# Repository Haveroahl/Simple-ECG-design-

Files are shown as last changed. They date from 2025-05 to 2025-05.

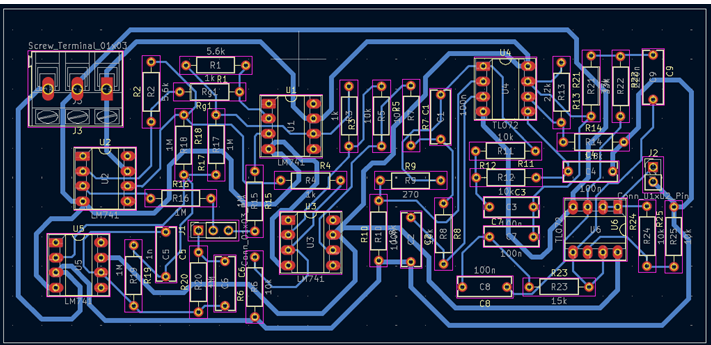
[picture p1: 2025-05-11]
Layout_ECG.png

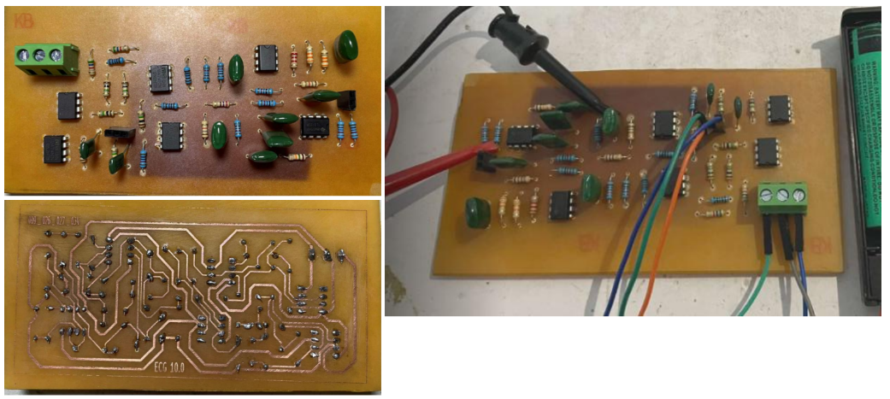
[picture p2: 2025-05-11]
PCB_ECG.png

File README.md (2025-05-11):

# Simple ECG design
#This is a group project focused on designing a simple ECG signal acquisition circuit. The initial design used the u741 operational amplifier, and later improvements were made using the TL072 for enhanced performance.

# Flow 
• Researched and analyzed the components of a basic ECG circuit, including an instrumentation amplifier, a 4th-order low-pass Sallen-Key filter, and a twin-T notch filter using the u741 OpAmp.<br>
• Calculated appropriate component values for circuit design, simulated ECG waveforms with added noise using LTspice, and tested the circuit on a breadboard.<br>
• Designed schematic and PCB layout, and assembled the circuit on a PCB.

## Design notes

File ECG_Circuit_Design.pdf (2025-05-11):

# THIẾT KẾ MẠCH Y SINH ECG

GIÁO VIÊN HƯỚNG DẪN: LÊ ĐỨC HÙNG

HỌ VÀ TÊN | MSSV | NHIỆM VỤ
Lê Minh Đức | 22200034 | Thiết kế, testboard, vẽ schematic, vẽ layout
Lê Thành Đạt | 22200026 | Testboard, hàn mạch PCB, cung cấp linh kiện
Nguyễn Hữu Đạt | 22200027 | Thiết kế, mô phỏng, testboard, hàn mạch PCB
Đặng Gia Bảo | 22200009 | Tìm hiểu nội dung, tính toán, thiết kế presentation

## 3. Ráp mạch: - Testboard - PCB - Kiểm tra

### 2. Thiết kế mạch: - Mạch khuếch đại vi sai - Mạch lọc thấp qua - Mạch lọc Notch - Mô phỏng

# MỤC LỤC

### 1. Giới thiệu: - Mục tiêu đồ án - Tổng quan về ECG

## 4. Kết luận: - Đánh giá - Hướng phát triển

# 1. GIỚI THIỆU

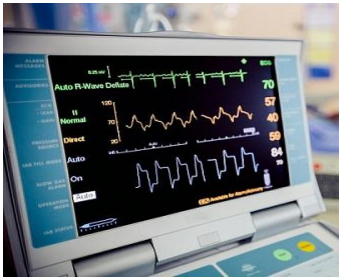
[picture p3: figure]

Đây là một đồ án trong lĩnh vực điện tử y sinh, tập trung vào thiết kế mạch tích hợp để thu nhận và xử lý tín hiệu ECG (điện tâm đồ).
Lý do chọn đề tài: ECG là công cụ quan trọng trong chẩn đoán bệnh tim mạch; thiết kế mạch tích hợp giúp nâng cao độ chính xác và hiệu quả của thiết bị y tế.

# MỤC TIÊU ĐỒ ÁN

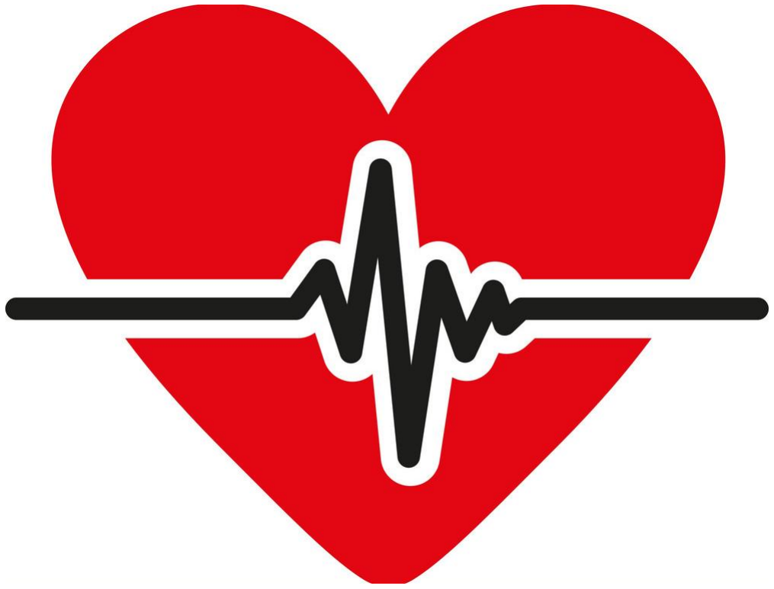
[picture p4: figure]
• Mục tiêu cụ thể: + Tìm hiểu tín hiệu ECG và yêu cầu kỹ thuật. + Thiết kế, mô phỏng các phần mạch (khuếch đại, lọc thấp qua, lọc Notch). +Lắp ráp và kiểm tra mạch thực tế. +Đánh giá hiệu suất mạch theo tiêu chuẩn y tế.

Mục tiêu chính:
- Thiết kế một mạch y sinh ECG đơn giản dùng để thu
nhận, khuếch đại tín hiệu
ECG và lọc nhiễu.

# MỤC TIÊU ĐỒ ÁN

Mục tiêu cụ thể:
- Tìm hiểu tín hiệu ECG và yêu cầu kỹ thuật.
- Thiết kế, tính toán và mô phỏng các phần mạch (khuếch đại, lọc thấp qua, lọc Notch).
- Ráp mạch testboard và kiểm tra.
- Làm mạch PCB.

# TỔNG QUAN VỀ ECG

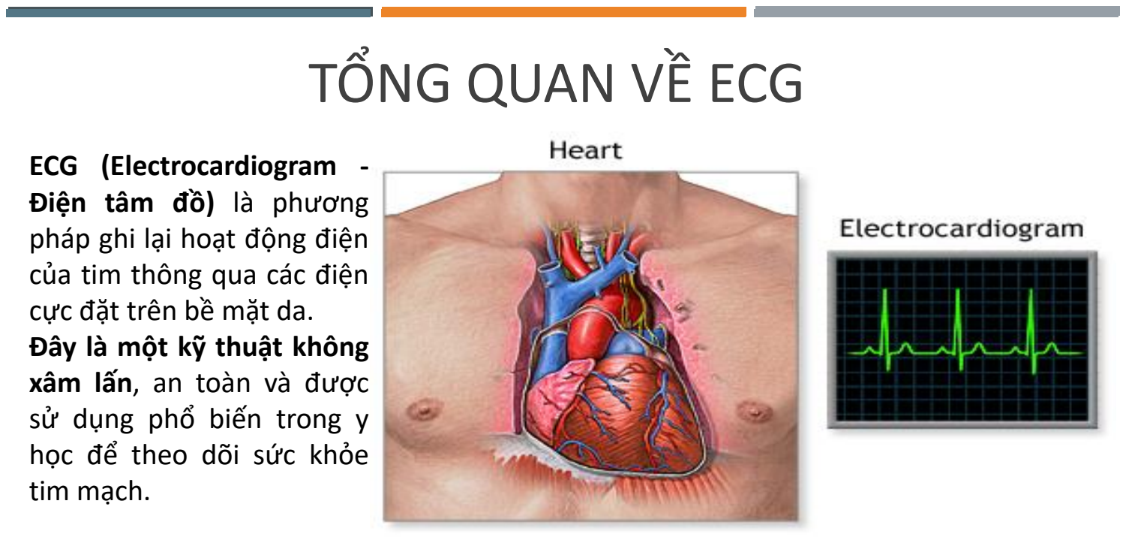
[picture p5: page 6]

ECG (Electrocardiogram -
Điện tâm đồ) là phương
pháp ghi lại hoạt động điện của tim thông qua các điện cực đặt trên bề mặt da.
Đây là một kỹ thuật không
xâm lấn, an toàn và được
sử dụng phổ biến trong y
học để theo dõi sức khỏe
tim mạch.

Ứng dụng:
- Theo dõi nhịp tim.
- Phát hiện các bất thường như rối loạn nhịp tim,
thiếu máu cơ tim hoặc
các bệnh lý tim mạch
khác.
- Hỗ trợ chuẩn đoán
nhanh khi cấp cứu.

# TỔNG QUAN VỀ ECG

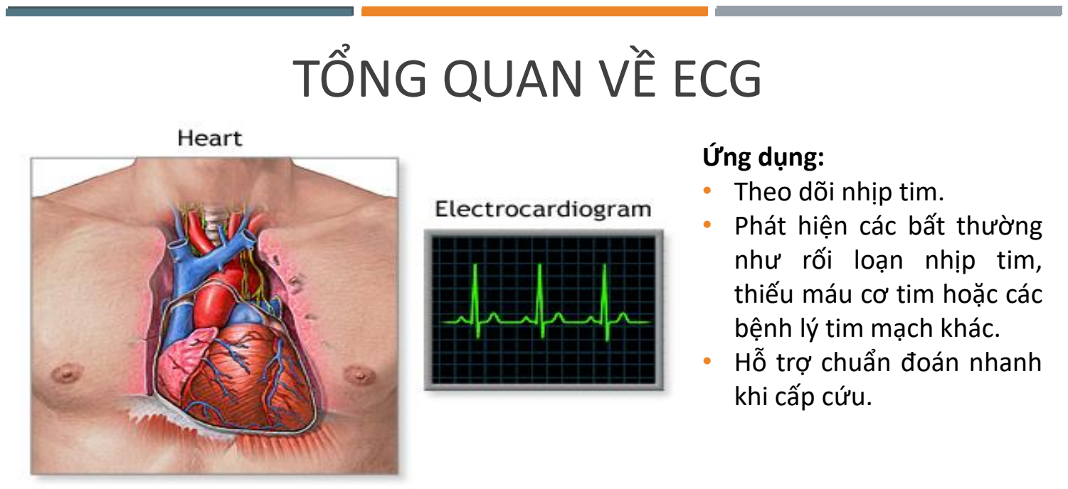
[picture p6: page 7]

ECG (Electrocardiogram -
Điện tâm đồ) là phương
pháp ghi lại hoạt động điện của tim thông qua các điện cực đặt trên bề mặt da. Đây là một kỹ thuật không xâm
lấn, an toàn và được sử dụng phổ biến trong y học để theo dõi sức khỏe tim mạch.

Ứng dụng:
- Theo dõi nhịp tim.
- Phát hiện các bất thường như rối loạn nhịp tim,
thiếu máu cơ tim hoặc các
bệnh lý tim mạch khác.
- Hỗ trợ chuẩn đoán nhanh
khi cấp cứu.

# TỔNG QUAN VỀ ECG

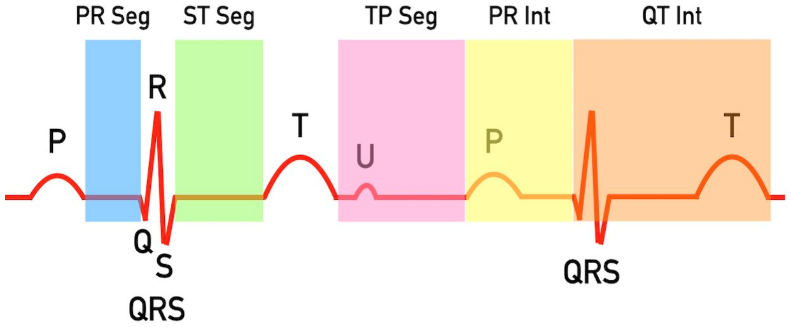
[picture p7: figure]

Đặc điểm tín hiệu ECG:
- Dải tần số(0.05-150Hz):
Gồm sóng P(khử cực tâm nhĩ), sóng T(tái cực tâm thất) có tần số thấp(0.05-1Hz) và sóng QRS(Khử cực tâm thất) có tần số cao(1-150Hz)
- Biên độ:
Tín hiệu ECG rất nhỏ, chỉ từ 0.5mV đến 5mV.

# TỔNG QUAN VỀ ECG

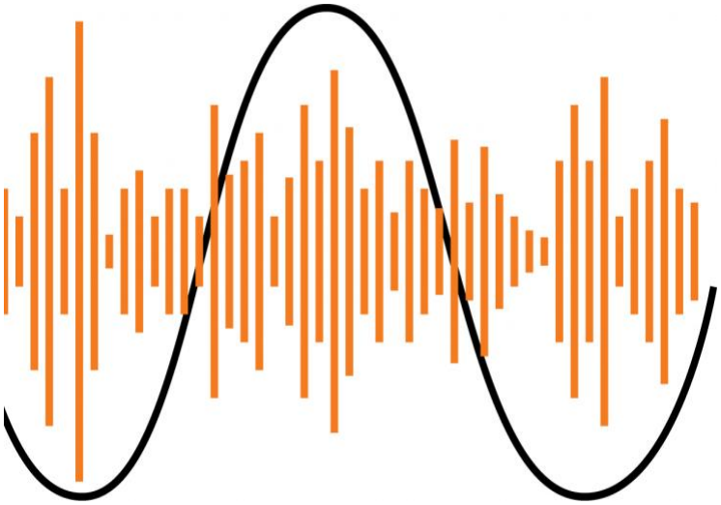
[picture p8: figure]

Nhiễu thường gặp:
- Nhiễu 50Hz: Có biên độ lớn(50mV) so với tín hiệu ECG, xuất hiện do nguồn AC trong môi trường.
- Nhiễu cơ bắp: Có tần số cao(>100Hz), biên độ phụ thuộc vào cường độ vận động.
- Nhiễu chuyển động: Do sự di chuyển của bệnh nhân hoặc các điện cực bị xê dịch.

Mạch khuếch đại vi sai (Instrumental
Amplifier):
Gồm 2 tầng:
- Tầng đầu là Buffer với ngõ vào V1 và V2.
- Tầng hai là khuếch đại vi sai cho ra output phù hợp với các chức năng đo.

# 2. THIẾT KẾ MẠCH

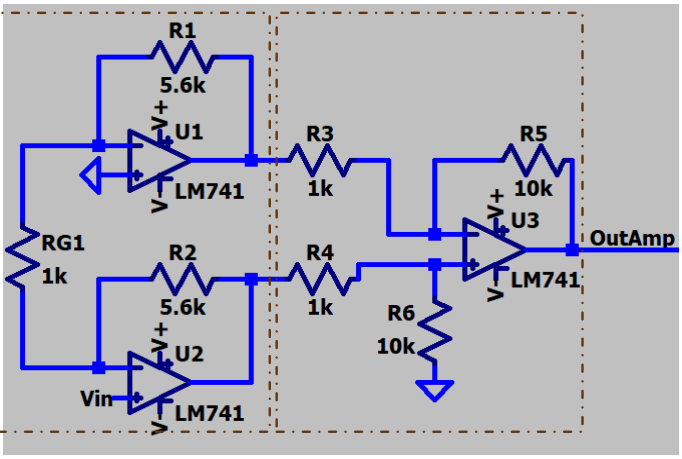
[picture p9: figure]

Buffer Khuếch đại

# 2. THIẾT KẾ MẠCH

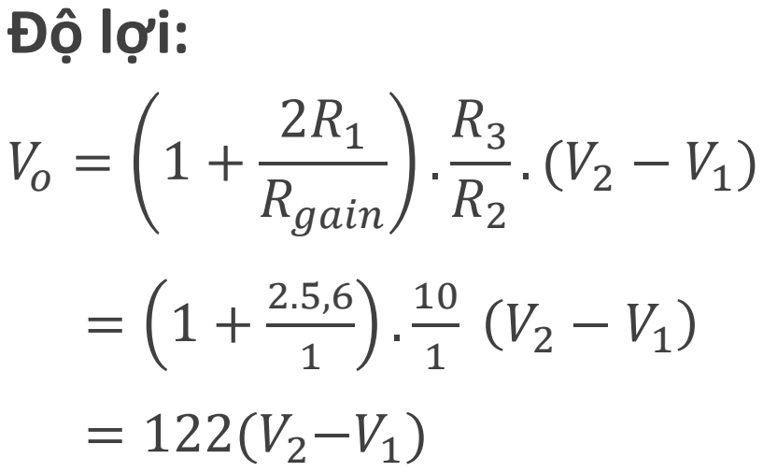
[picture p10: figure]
Độ lợi:; Rgain
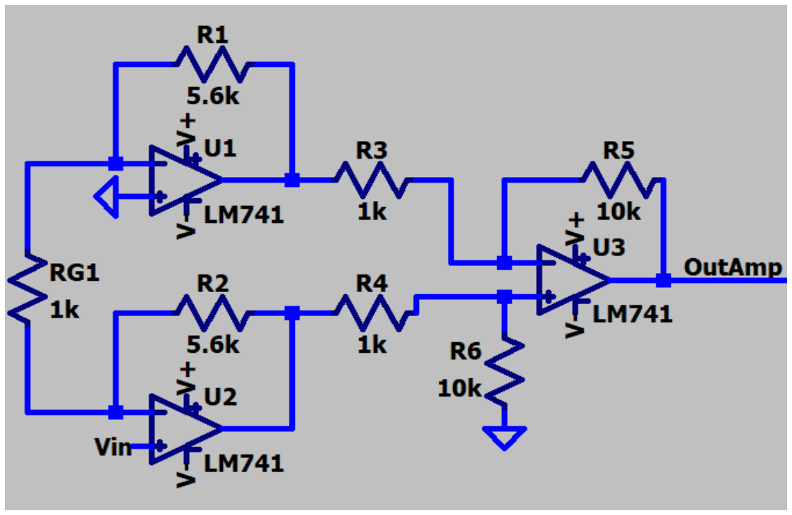
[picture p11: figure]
Mạch khuếch đại vi sai (Instrumental Amplifier):; Gồm 2 tầng:; • Tầng đầu là Buffer với ngõ vào V1 và V2.; • Tầng hai là khuếch đại vi sai cho ra output phù hợp với các chức năng đo.

# 2. THIẾT KẾ MẠCH

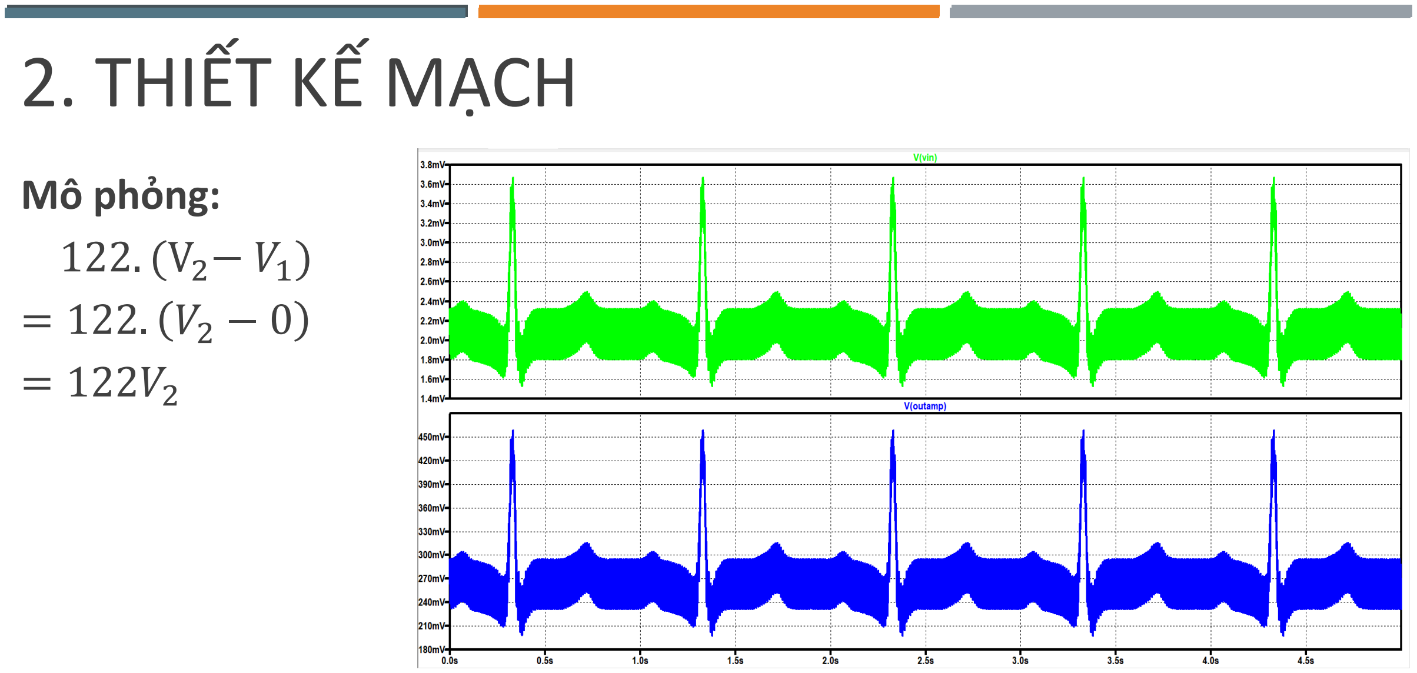
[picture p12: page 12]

Mạch khuếch đại vi sai (Instrumental
Amplifier):
Gồm 2 tầng:
- Tầng đầu là Buffer với ngõ vào V1 và V2.
- Tầng hai là khuếch đại vi sai cho ra output phù hợp với các chức năng đo.

Độ lợi:

Vo = 1 +

2R1

Rgain

R3
R2

. (V2 − V1)

= 1 +

2.5,6
1

10
1

V2 − V1

= 122(V2−V1)

Mô phỏng:
122. (V2− V1)
= 122. V2 − 0
= 122V2

# 2. THIẾT KẾ MẠCH

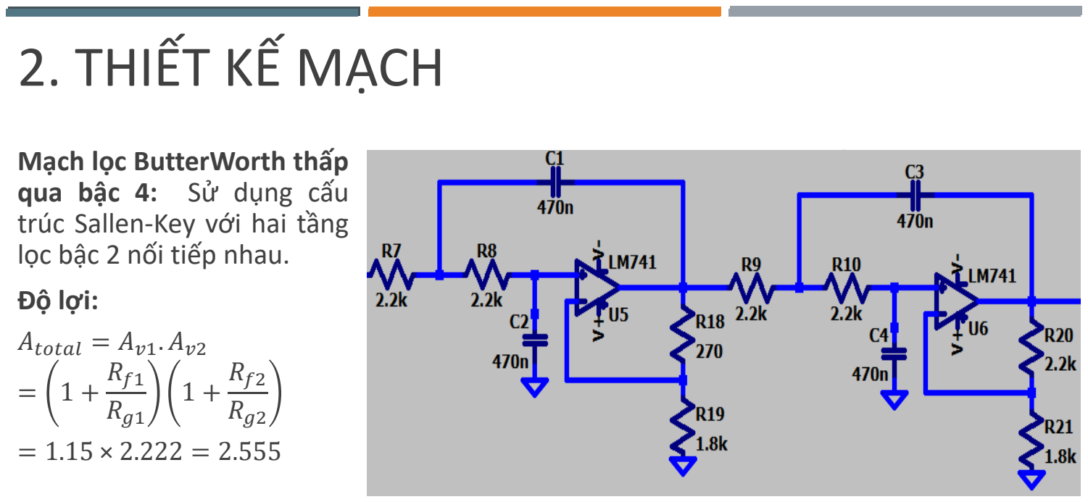
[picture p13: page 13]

Tần số cắt
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
π. 2200.470. 10

−

9
≈ 154Hz →Các tần số trên 154Hz sẽ

bị lọc bỏ

Mạch lọc ButterWorth thấp
qua bậc

4

: Sử dụng cấu
trúc Sallen

-Key với hai tầng
lọc bậc

2 nối tiếp nhau
Độ lợi

:

Atotal

=

A
v
1. A
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
1.15
×

2.222

=

2.555

# 2. THIẾT KẾ MẠCH

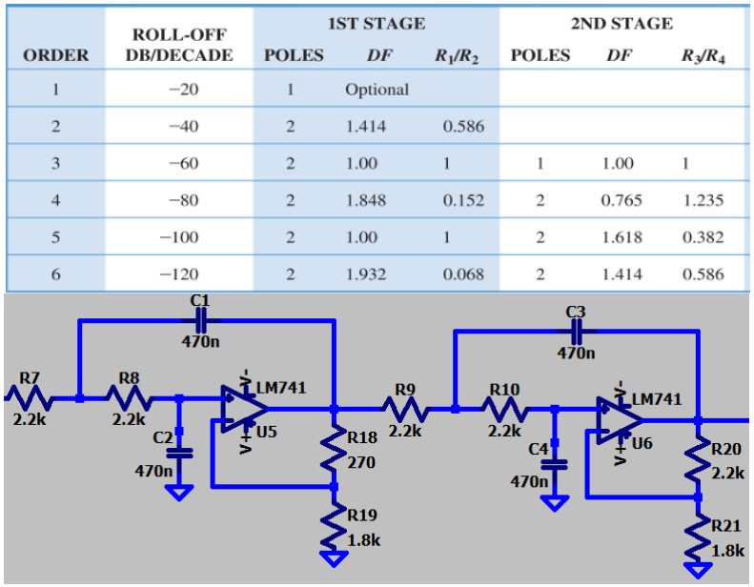
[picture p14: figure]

Hệ số bộ hồi tiếp mạch lọc

Damping Factor:
R2 = 1.8kΩ
ÞR1 = 273.6Ω
ÞChọn R18 = 270Ω

R4 = 1.8kΩ
ÞR3 = 2.223kΩ
ÞChọn R20 = 2.2kΩ

# 2. THIẾT KẾ MẠCH

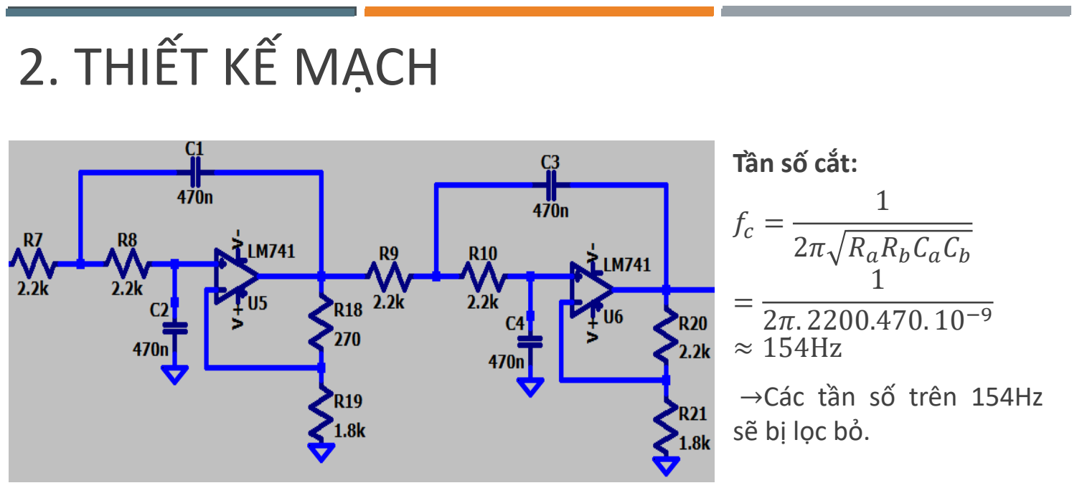
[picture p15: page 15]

Tần số cắt
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
π. 2200.470. 10

−

9
≈ 154Hz →Các tần số trên 154Hz

sẽ bị lọc bỏ

Mạch lọc Butter Worth thấp qua bậc

4

: Sử dụng cấu trúc
Sallen

-Key với hai tầng lọc bậc
2 nối tiếp nhau
Độ lợi

:

Atotal

=

A
v
1. A
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
1.15
×

2.222

=

2.555

# 2. THIẾT KẾ MẠCH

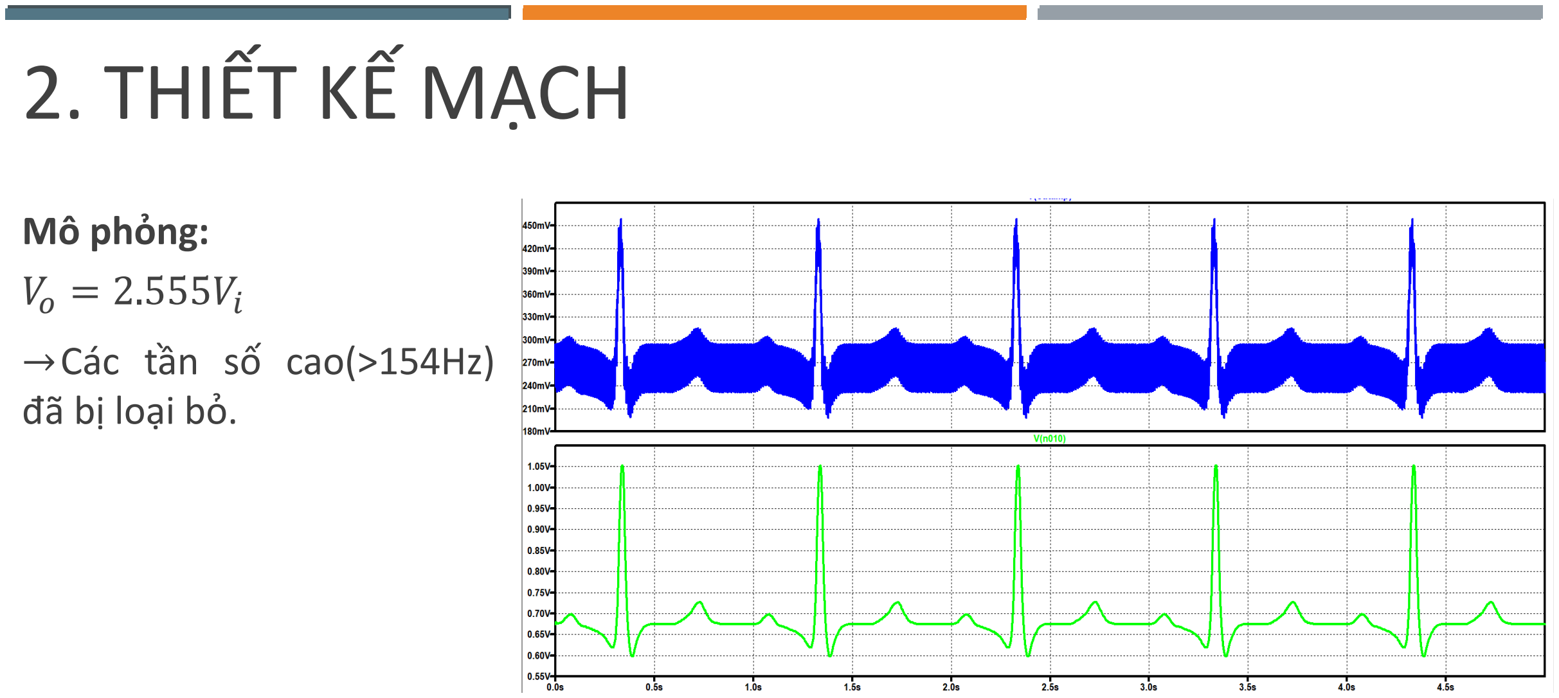
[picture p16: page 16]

Tần số cắt
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
π. 2200.470. 10

−

9
≈ 154Hz →Các tần số trên 154Hz sẽ

bị lọc bỏ

Mạch lọc Butter Worth thấp qua bậc

4

: Sử dụng cấu trúc
Sallen

-Key với hai tầng lọc bậc
2 nối tiếp nhau
Độ lợi

:

Atotal

=

A
v
1. A
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
1.15
×

2.222

=

2.555

Mô phỏng

:
Vo

=

2.555

Vi
→Các tần số cao(>154Hz)
đã bị loại bỏ

# 2. THIẾT KẾ MẠCH

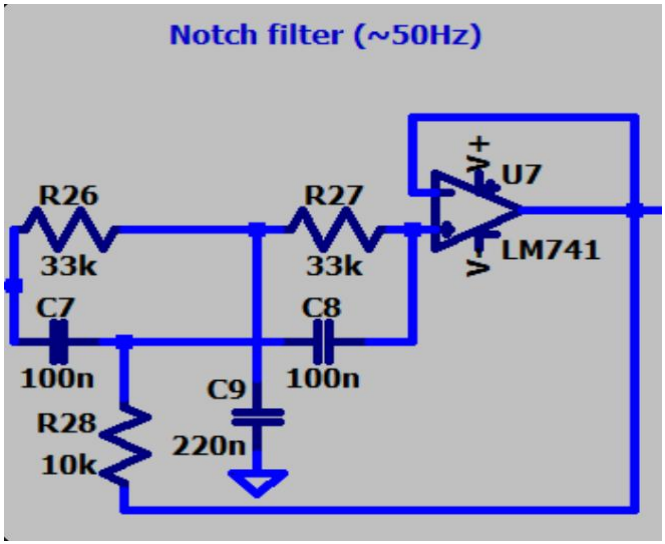
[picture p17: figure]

Mạch lọc Notch: Dùng để lọc nhiễu tần số 50Hz.
Hệ số phẩm chất Q:

Q =

1

2(

R28
R26 + R27)

=

33
10

= 3.3

Tần số cắt:

fnotcℎ =

1
2πRC

≈ 48.24Hz

# 2. THIẾT KẾ MẠCH

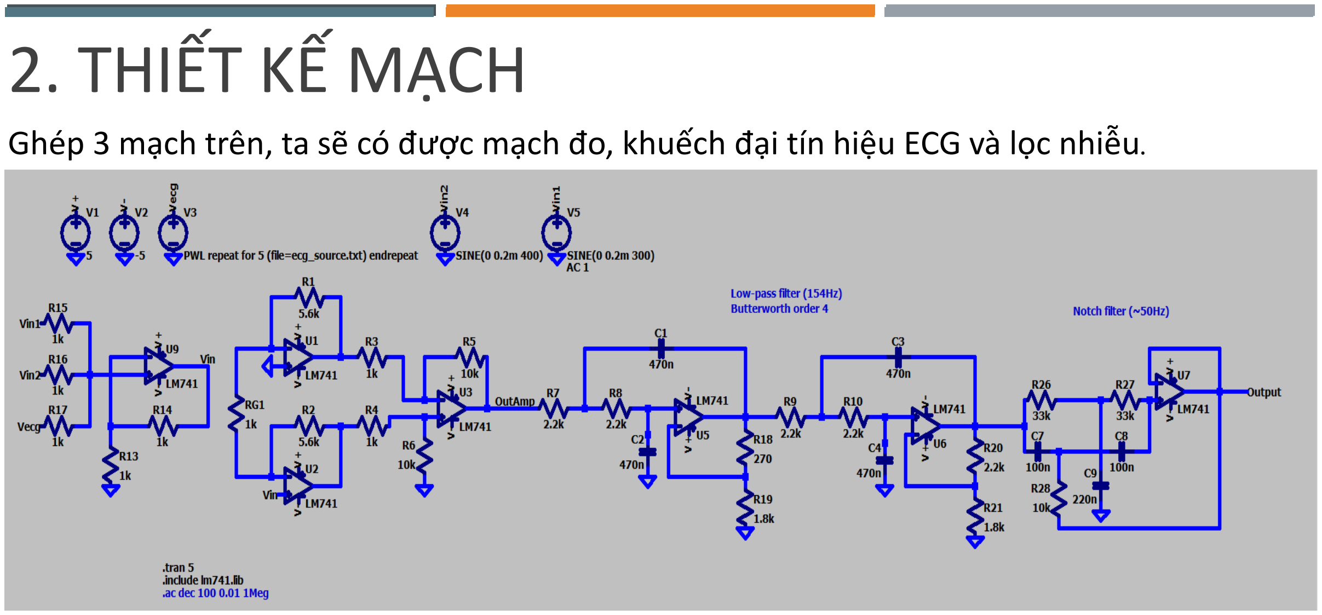
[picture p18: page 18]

Vin (ECG và các loại nhiễu) | Vout(Khuếch đại và lọc nhiễu)
Nhận xét: Ngõ ra được khuếch đại, lọc nhiễu và vẫn có đủ các thành phần sóng P, sóng T và sóng QRS.

Ghép 3 mạch trên, ta sẽ có được mạch đo, khuếch đại tín hiệu ECG và lọc nhiễu.

# 2. THIẾT KẾ MẠCH

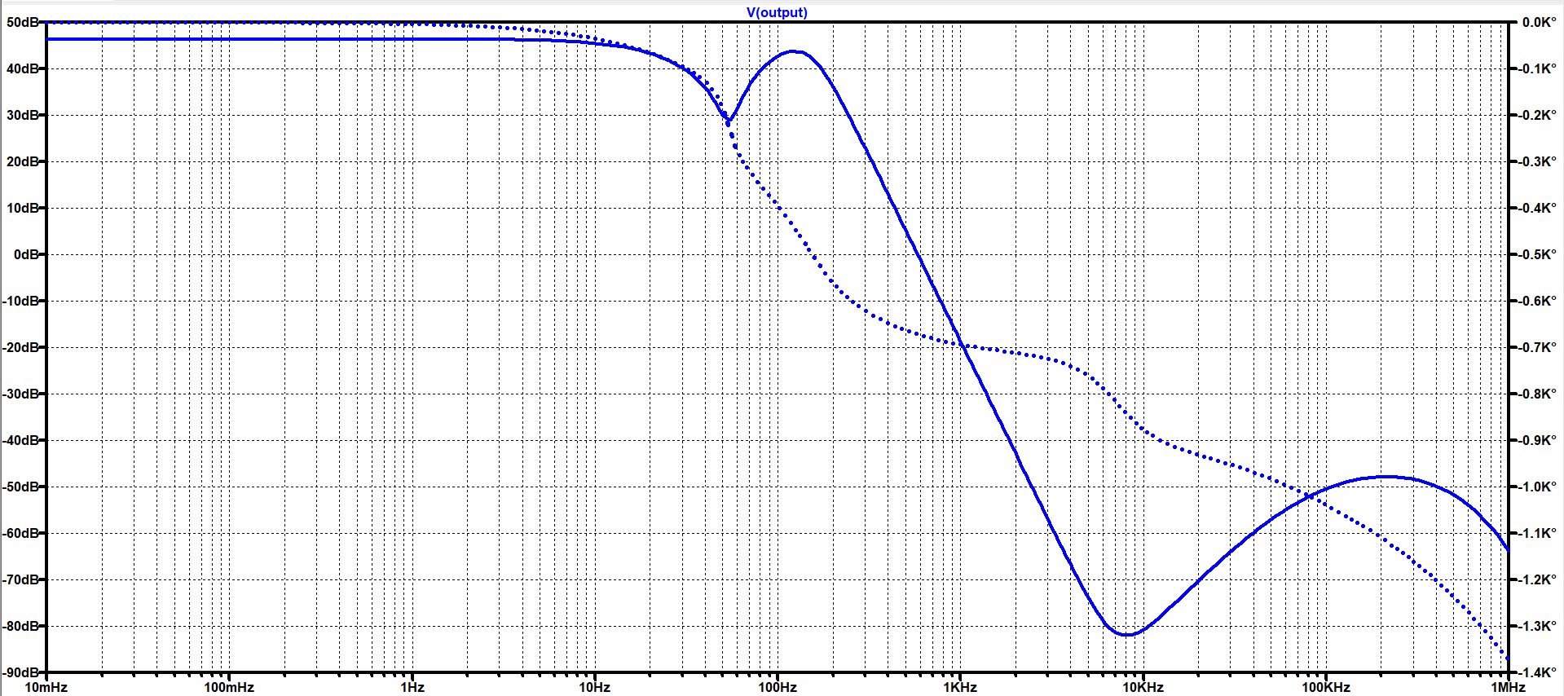
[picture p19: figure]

Đáp ứng tần số

# 2. THIẾT KẾ MẠCH

Vin (ECG và các loại nhiễu) | Vout(Khuếch đại và lọc nhiễu)
Nhận xét: Ngõ ra được khuếch đại, lọc nhiễu và vẫn có đủ các thành phần sóng P, sóng T và sóng QRS.

# 3. RÁP MẠCH

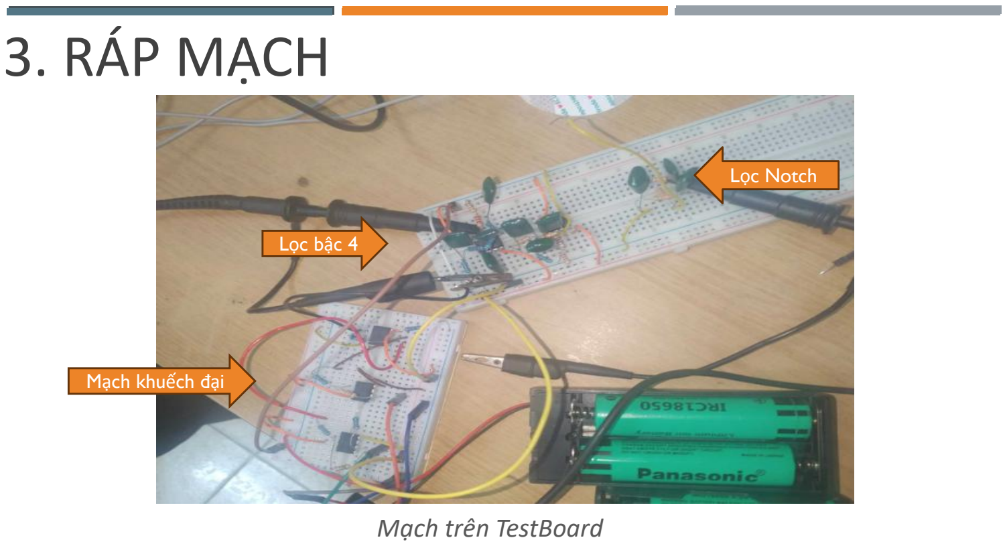
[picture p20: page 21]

Lọc bậc 4

Mạch khuếch đại

Lọc Notch

Mạch trên TestBoard

# 3.RÁP MẠCH: SCHEMATIC

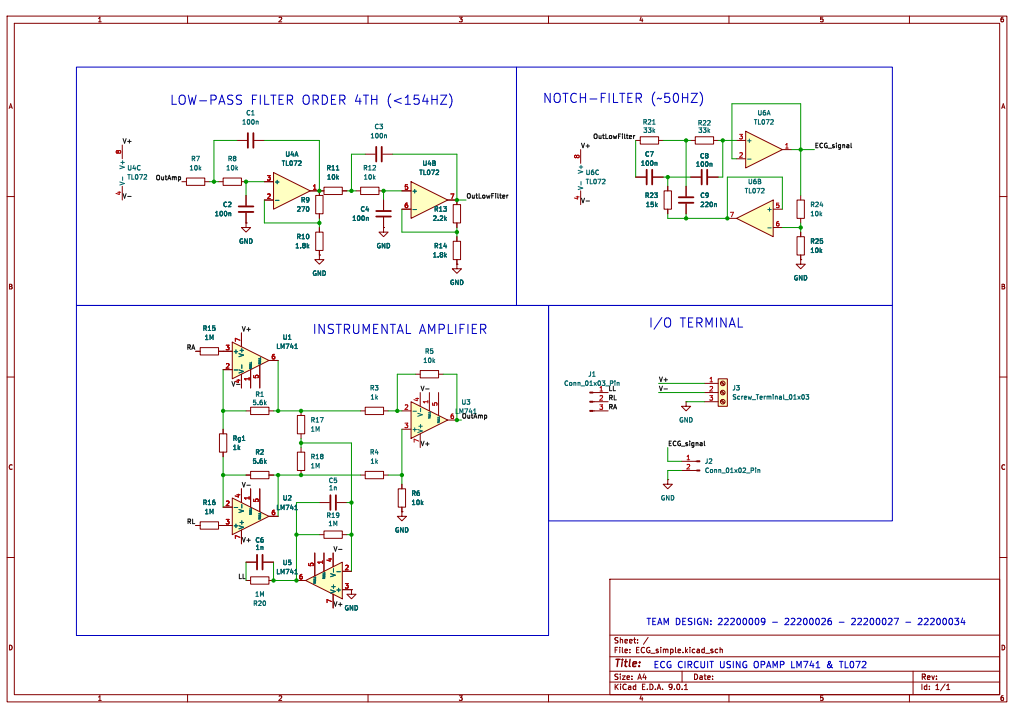
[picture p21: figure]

# 3.RÁP MẠCH: LAYOUT

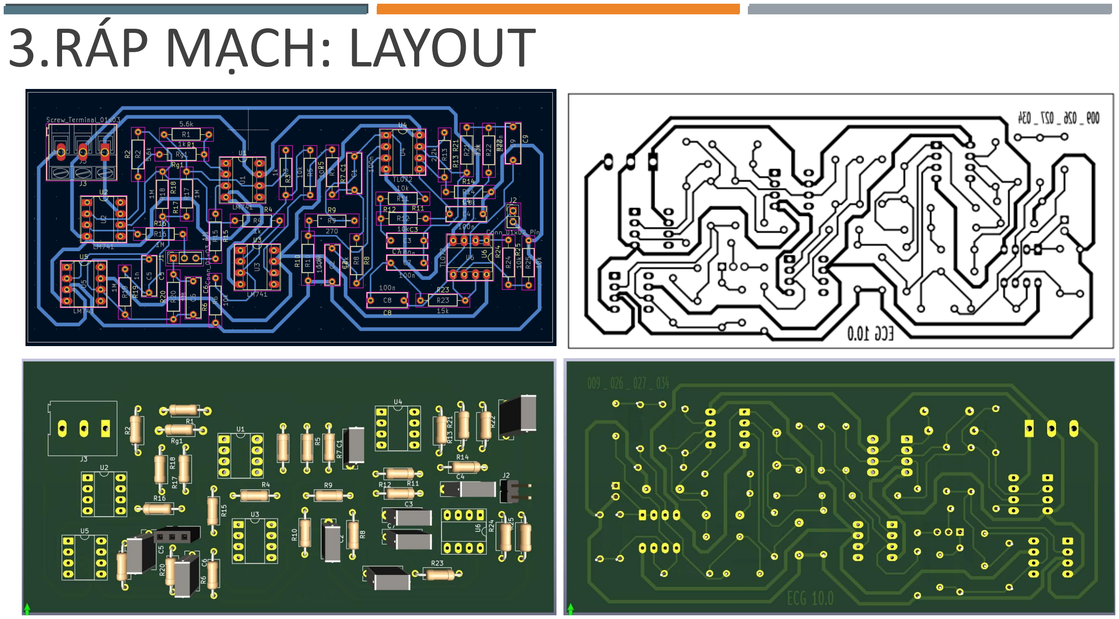
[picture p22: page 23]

# 3.RÁP MẠCH: PCB

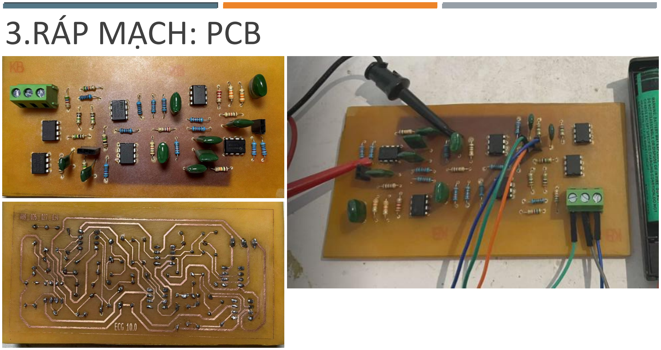
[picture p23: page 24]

# 3. RÁP MẠCH

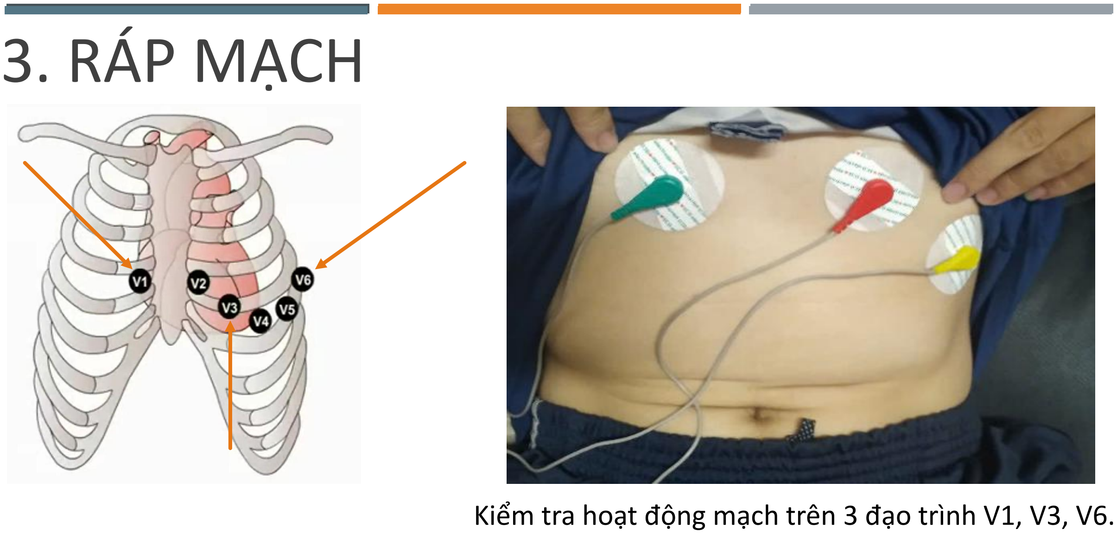
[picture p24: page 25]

Kiểm tra hoạt động mạch trên 3 đạo trình V1, V3, V6.

# 3. RÁP MẠCH

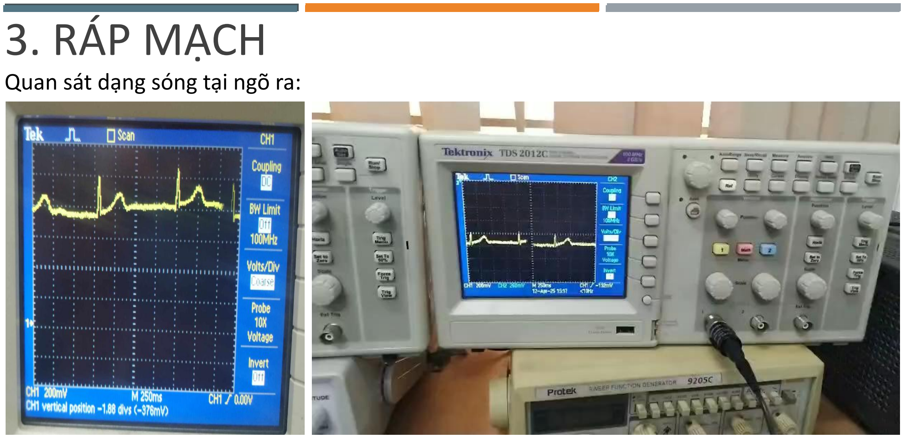
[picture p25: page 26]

Quan sát dạng sóng tại ngõ ra:

# 4. KẾT LUẬN

Đánh giá:
- Tín hiệu ECG được khuếch đại, các nhiễu cao tần, nhiễu 50Hz được giảm thiểu.
- Dạng song P, QRS, T được hiển thị trên Oscilloscope.
Điểm mạnh:
- Phù hợp với mục tiêu đề ra.
- Sử dụng nguồn 9V để hạn chế nhiễu 50Hz.
- Từ mô phỏng đến PCB, tín hiệu cho ra đầu ra gần giống với mô phỏng.

Khó khan gặp phải:
- Tín hiệu: Vẫn tồn tại nhiễu quan sát được trên Oscilloscope.
- PCB: Một số linh kiện được bố trí chưa tối ưu gây khó khan khi hàn.
Kết luận:
- Thành công trong việc xuất ra tín hiệu ECG.

# ĐỊNH HƯỚNG PHÁT TRIỂN

Cải tiến kỹ thuật:
- Tăng độ chính xác: Thay mạch khuếch đại bằng AD620, AD8232,..
- Giảm nhiễu: Cải tiến bộ lọc bằng lọc số.

Tích hợp công nghệ:

- Tích hợp ADC chuyển dữ liệu ECG thành dữ liệu số.
- Kết nối với vi điều khiển để in ra monitor.

Ứng dụng thực tế:

- Cảm biến y sinh không dây.
- Kết nối với hệ thống y tế từ xa để bác sĩ theo dõi tình trạng bệnh nhân qua Internet

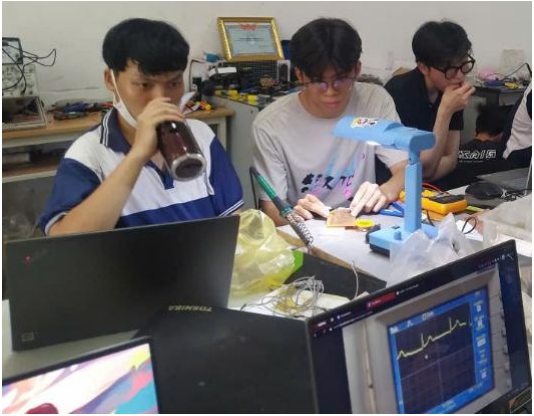
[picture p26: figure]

## THANK YOU FOR LISTENING

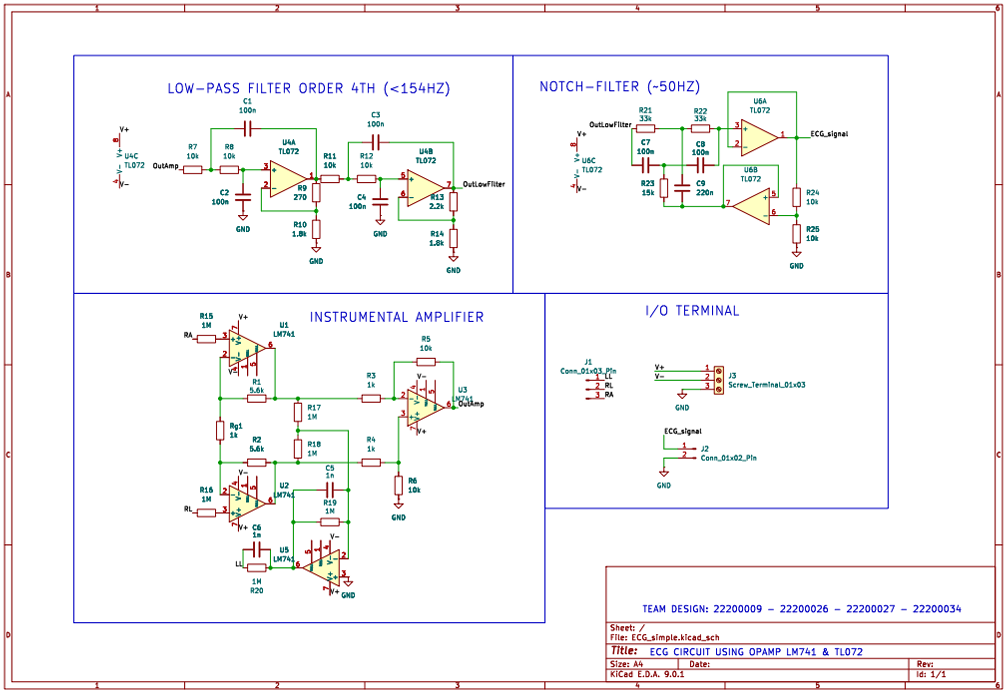
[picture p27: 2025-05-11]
Schematic_ECG.png

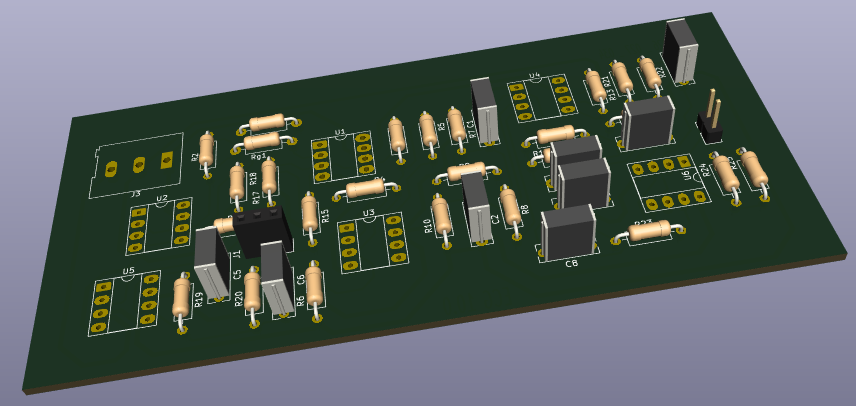
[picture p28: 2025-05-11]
3Dlayout_ECG.png

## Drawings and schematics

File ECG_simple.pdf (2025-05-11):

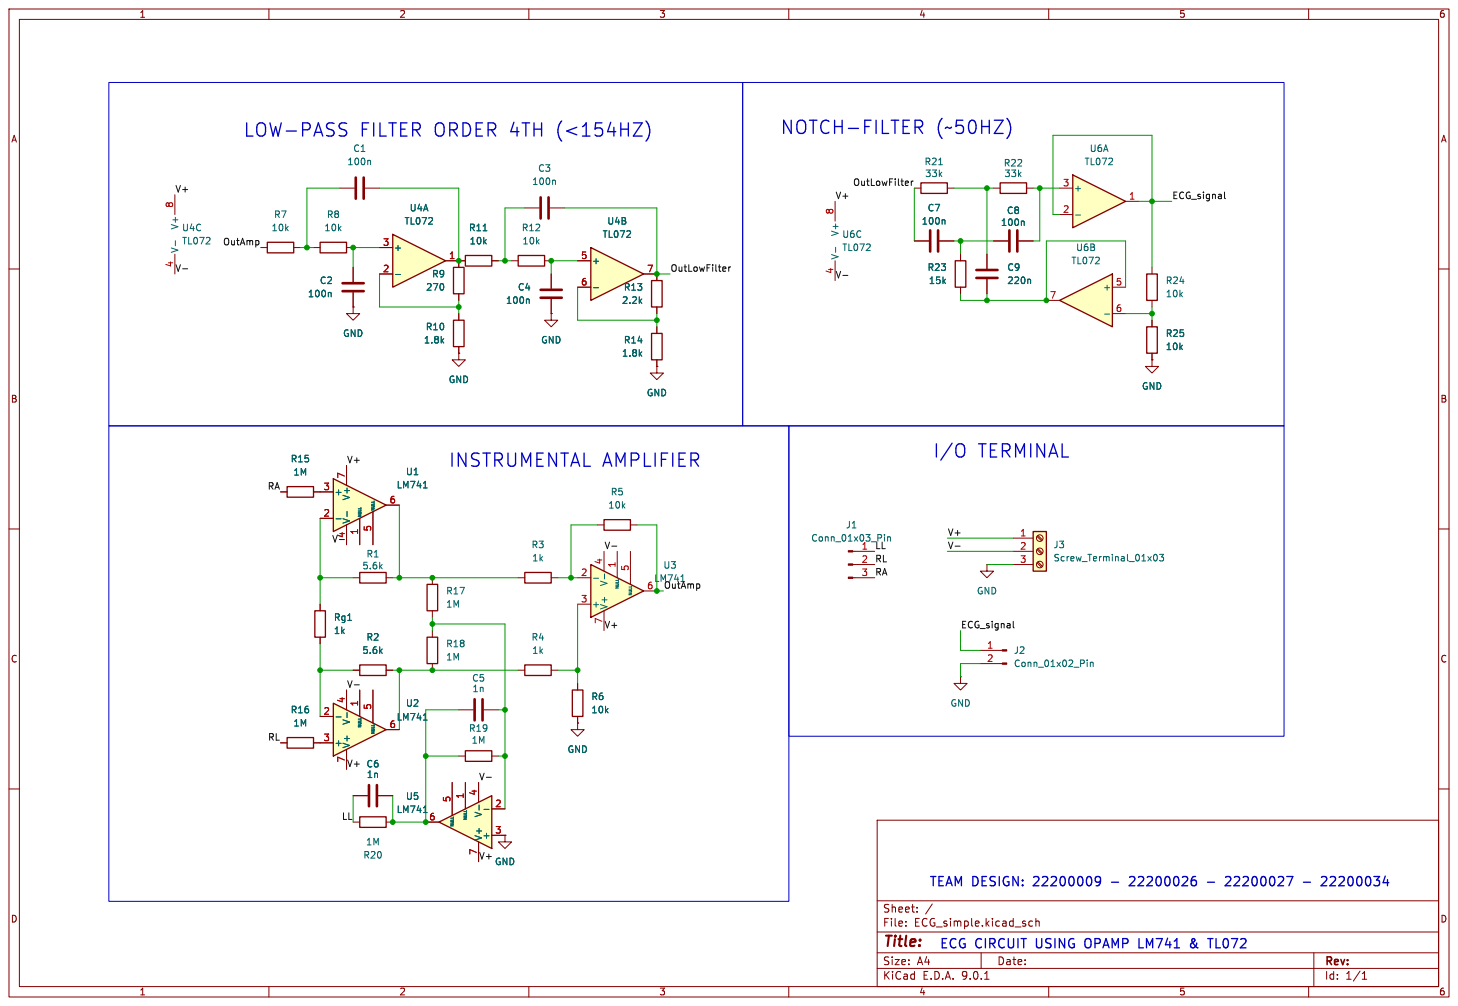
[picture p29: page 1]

Id: 1/1 Title: File: ECG_simple.kicad_sch Sheet: / R16

ECG CIRCUIT USING OPAMP LM741 & TL072

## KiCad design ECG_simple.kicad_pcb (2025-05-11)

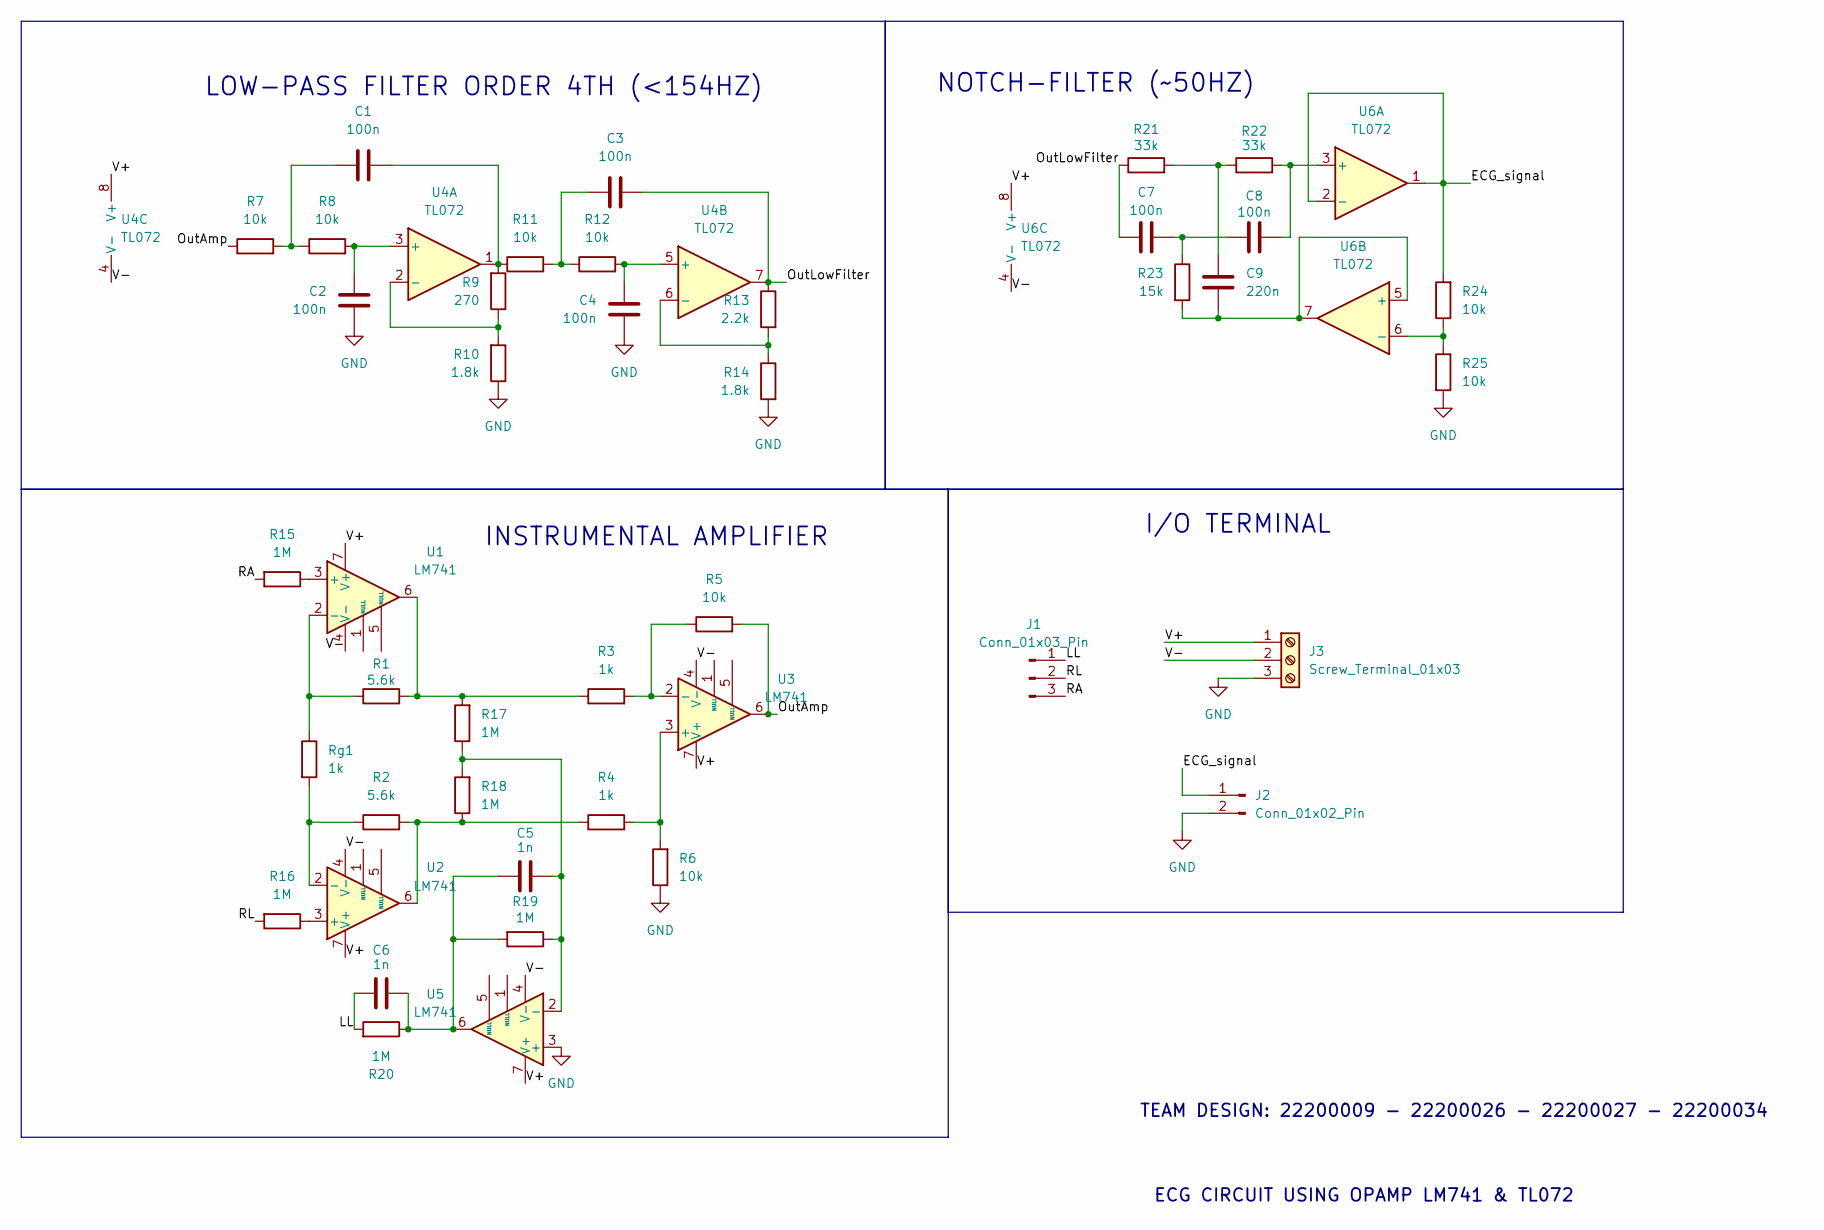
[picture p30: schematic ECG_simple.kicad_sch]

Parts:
C1, C2, C3, C4, C7, C8: 100n; C_Rect_L9.0mm_W3.2mm_P7.50mm_MKT
C5, C6: 1n; C_Rect_L9.0mm_W3.2mm_P7.50mm_MKT
C9: 220n; C_Rect_L9.0mm_W3.2mm_P7.50mm_MKT
J1: Conn_01x03_Pin; PinSocket_1x03_P2.54mm_Vertical
J2: Conn_01x02_Pin; PinHeader_1x02_P2.54mm_Vertical
J3: Screw_Terminal_01x03; TerminalBlock_Altech_AK300-3_P5.00mm
R1, R2: 5.6k; R_Axial_DIN0207_L6.3mm_D2.5mm_P10.16mm_Horizontal
R3, R4: 1k; R_Axial_DIN0207_L6.3mm_D2.5mm_P10.16mm_Horizontal
R5, R6, R7, R8, R11, R12, R24, R25: 10k; R_Axial_DIN0207_L6.3mm_D2.5mm_P10.16mm_Horizontal
R9: 270; R_Axial_DIN0207_L6.3mm_D2.5mm_P10.16mm_Horizontal
R10, R14: 1.8k; R_Axial_DIN0207_L6.3mm_D2.5mm_P10.16mm_Horizontal
R13: 2.2k; R_Axial_DIN0207_L6.3mm_D2.5mm_P10.16mm_Horizontal
R15, R16, R17, R18, R19, R20: 1M; R_Axial_DIN0207_L6.3mm_D2.5mm_P10.16mm_Horizontal
R21, R22: 33k; R_Axial_DIN0207_L6.3mm_D2.5mm_P10.16mm_Horizontal
R23: 15k; R_Axial_DIN0207_L6.3mm_D2.5mm_P10.16mm_Horizontal
Rg1: 1k; R_Axial_DIN0207_L6.3mm_D2.5mm_P10.16mm_Horizontal
U1, U2, U3, U5: LM741; DIP-8_W7.62mm_Socket_LongPads
U4, U6: TL072; DIP-8_W7.62mm_Socket_LongPads

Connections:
/ECG_signal: J2.1, R24.2, U6.1, U6.2 (-)
/LL: C6.1, J1.1, R20.2
/OutAmp: R5.2, R7.1, U3.6
/OutLowFilter: C3.2, C7.2, R13.1, R21.1, U4.7
/RA: J1.3, R15.2
/RL: J1.2, R16.2
/V+: J3.1, U1.7 (V+), U2.7 (V+), U3.7 (V+), U4.8 (V+), U5.7 (V+), U6.8 (V+)
/V-: J3.2, U1.4 (V-), U2.4 (V-), U3.4 (V-), U4.4 (V-), U5.4 (V-), U6.4 (V-)
GND: C2.2, C4.2, J2.2, J3.3, R6.1, R10.1, R14.2, R25.2, U5.3 (+)
unnamed: C1.1, R7.2, R8.1
unnamed: C1.2, R9.2, R11.1, U4.1
unnamed: C3.1, R11.2, R12.1
unnamed: C5.1, C6.2, R19.2, R20.1, U5.6
unnamed: C7.1, C8.2, R23.1
unnamed: C9.1, R21.2, R22.1
unnamed: R1.2, R3.1, R17.2, U1.6
unnamed: R2.2, R4.1, R18.1, U2.6
unnamed: R15.1, U1.3 (+)
unnamed: R1.1, Rg1.1, U1.2 (-)
unnamed: R16.1, U2.3 (+)
unnamed: R2.1, Rg1.2, U2.2 (-)
unnamed: R4.2, R6.2, U3.3 (+)
unnamed: R3.2, R5.1, U3.2 (-)
unnamed: C2.1, R8.2, U4.3 (+)
unnamed: R9.1, R10.2, U4.2 (-)
unnamed: C4.1, R12.2, U4.5 (+)
unnamed: R13.2, R14.1, U4.6 (-)
unnamed: C5.2, R17.1, R18.2, R19.1, U5.2 (-)
unnamed: C8.1, R22.2, U6.3 (+)
unnamed: C9.2, R23.2, U6.5 (+), U6.7
unnamed: R24.1, R25.1, U6.6 (-)

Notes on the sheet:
INSTRUMENTAL AMPLIFIER
LOW-PASS FILTER ORDER 4TH (<154HZ)
ECG CIRCUIT USING OPAMP LM741 & TL072
I/O TERMINAL
TEAM DESIGN: 22200009 - 22200026 - 22200027 - 22200034
NOTCH-FILTER (~50HZ)

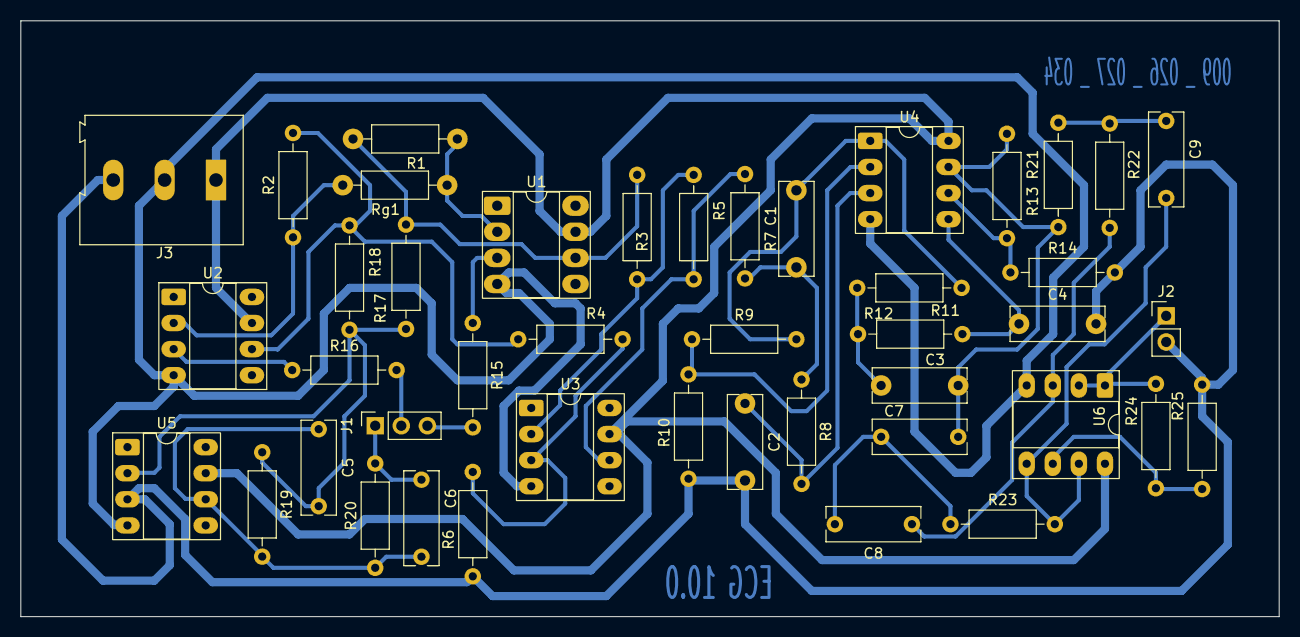
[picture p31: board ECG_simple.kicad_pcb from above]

Board: 2 copper layers, 122.5 x 58.0 mm, 44 parts (0 on the bottom side), 31 nets.
